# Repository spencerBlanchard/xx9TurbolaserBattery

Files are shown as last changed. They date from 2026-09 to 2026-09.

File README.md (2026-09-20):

# xx9TurbolaserBattery
Welcome to the XX-9 Heavy Turbolaser Battery. This was originally made to have audio but the module I was using had a small delay, which kind of killed the gameplay so I got rid of it completely. 
Vibe Coded. 
Runs on esp32 dev kit

A NOTE ABOUT USING THE SERVOS: the MG90S servos are continuous servos, which means you have to spend a gutwrenching number of hours calibrating them. If you want to redo the code and use positional servos, that's probably easier, but my wife says I'm not allowed to spend any more money on this project. 

Parts list if you want to build your own:

Heat Set Threaded Inserts:
https://www.amazon.com/dp/B0CS6VZYL8?ref=ppx_yo2ov_dt_b_fed_asin_title&th=1

Screws (for the inserts):
https://www.amazon.com/dp/B0FLKCP52N?ref=ppx_yo2ov_dt_b_fed_asin_title

-SG90 servo (1)
https://www.amazon.com/MELIFE-Micro-Servo-Plastic-Digital/dp/B0GTPGBW23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

-MG90S Servos (2)
https://www.amazon.com/Compatible-Raspberry-Project-Helicopter-Airplane/dp/B0925V3X2S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

-Joystick
https://www.adafruit.com/product/480

-Buttons
https://www.aliexpress.us/item/2251832838113879.html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

-TFT Display (also get the breakout board and ribbon)
https://www.adafruit.com/product/2090

(And resistors and wire and green leds and protoboard)

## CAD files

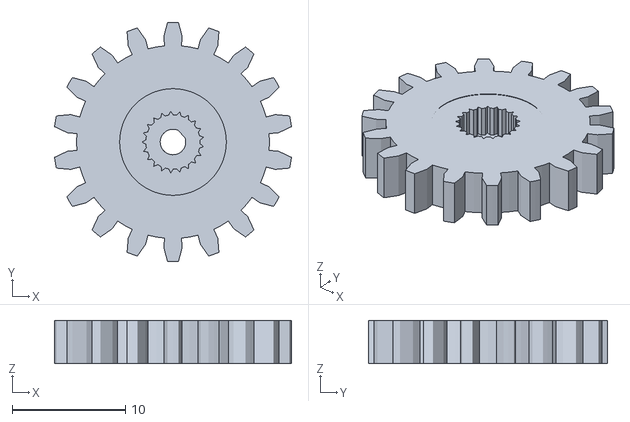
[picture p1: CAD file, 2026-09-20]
print_files/gear_yaw_v01.stl
20.9 x 21.1 x 3.81

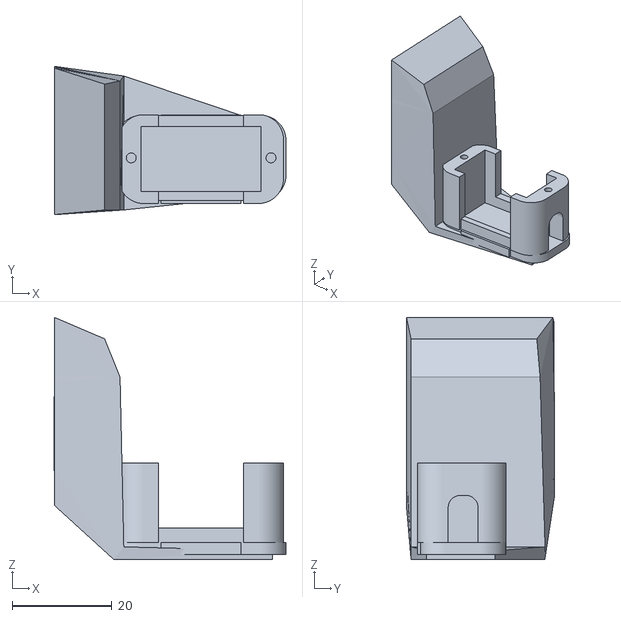
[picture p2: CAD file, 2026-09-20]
print_files/yawTopAddon_v01.stl
46.5 x 29.7 x 48.5

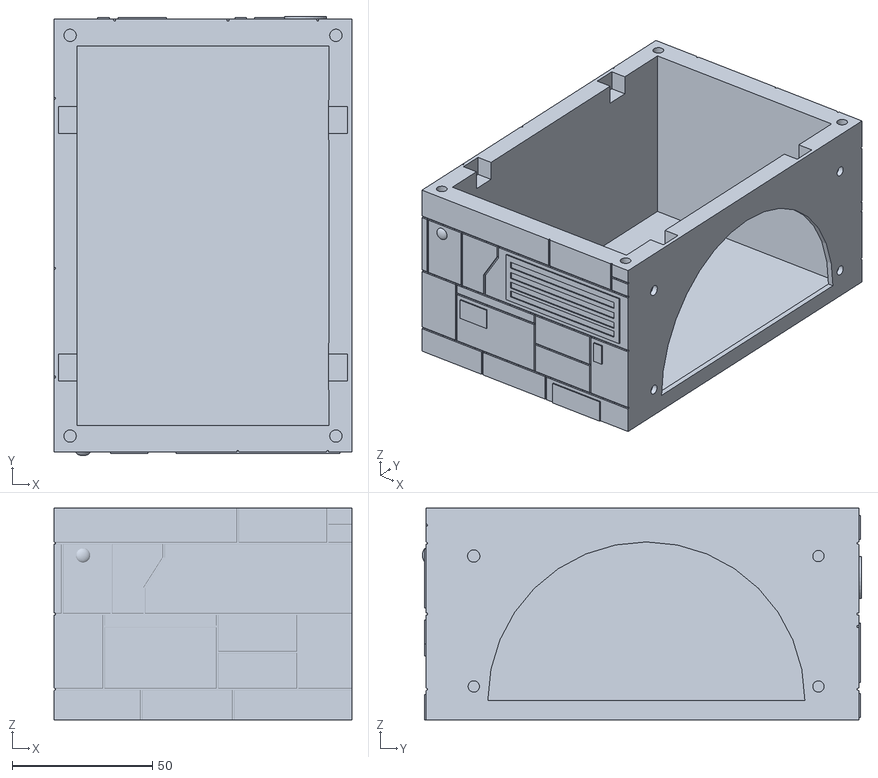
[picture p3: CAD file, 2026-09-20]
print_files/base_side_left_v01.stl
106.2 x 156.5 x 75.5

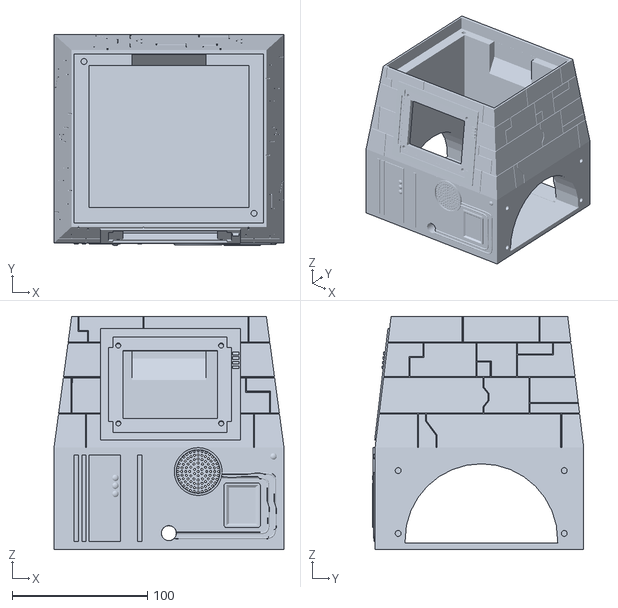
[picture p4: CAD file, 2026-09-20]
print_files/Base_v01.stl
170.1 x 156.4 x 172.4

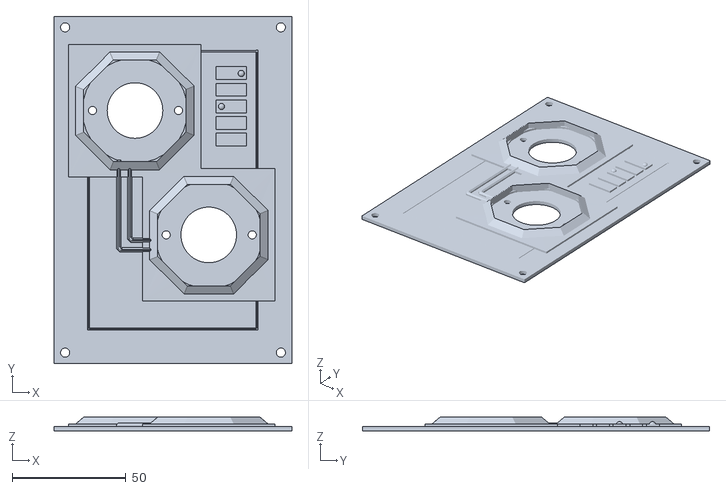
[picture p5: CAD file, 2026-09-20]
print_files/sideTop_buttons_v02.stl
104.3 x 152.3 x 6.06

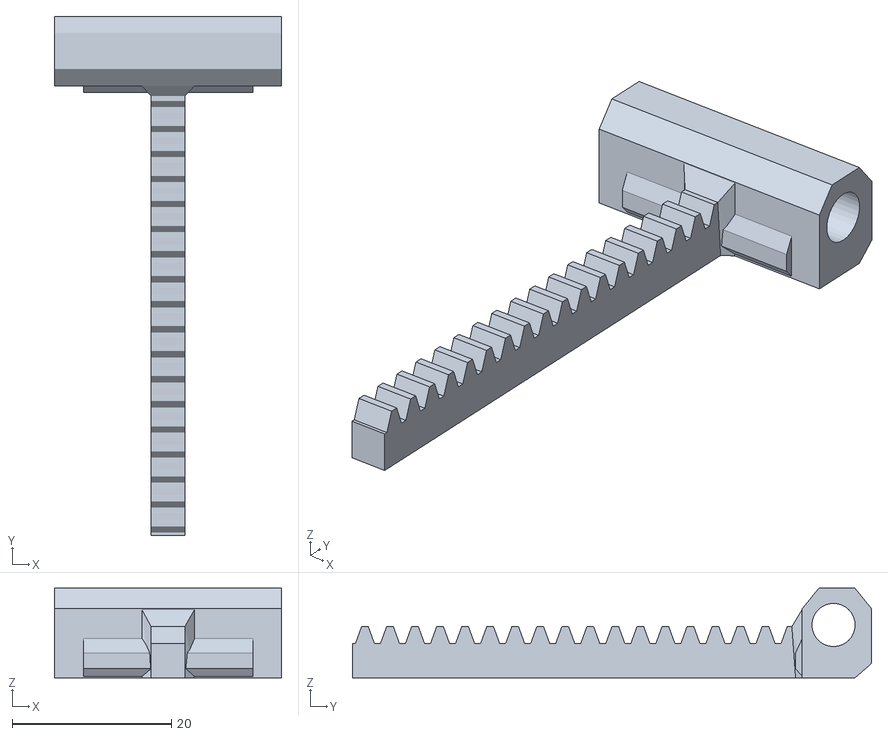
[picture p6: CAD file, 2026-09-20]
print_files/gear_linearActuator_straight_v01.stl
28.5 x 65.1 x 11.3

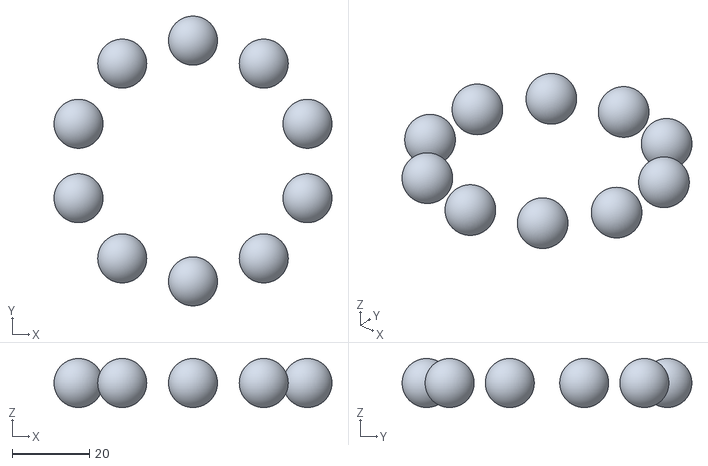
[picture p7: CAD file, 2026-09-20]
print_files/balls_v01.stl
72.0 x 75.1 x 12.7

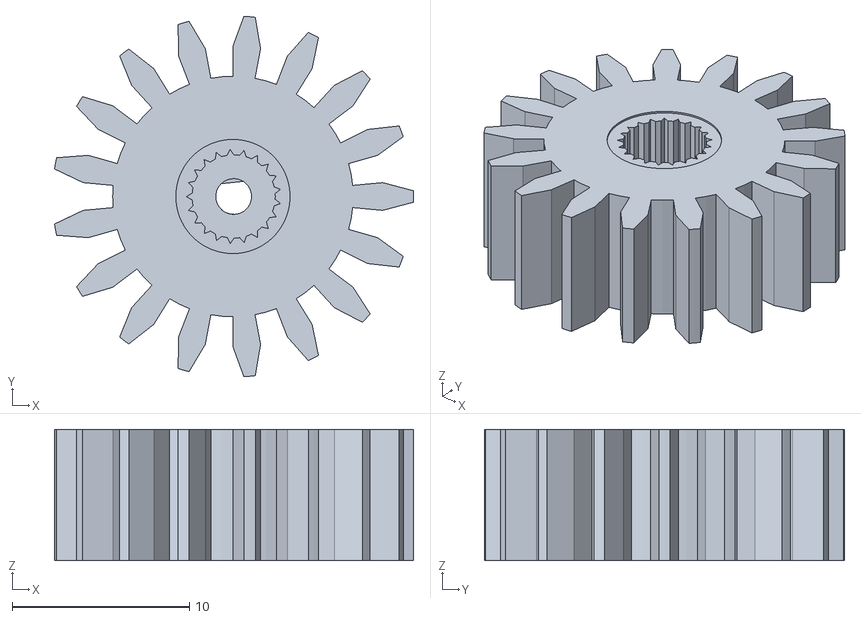
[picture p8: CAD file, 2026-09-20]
print_files/gear_pitch_v01.stl
20.2 x 20.3 x 7.40

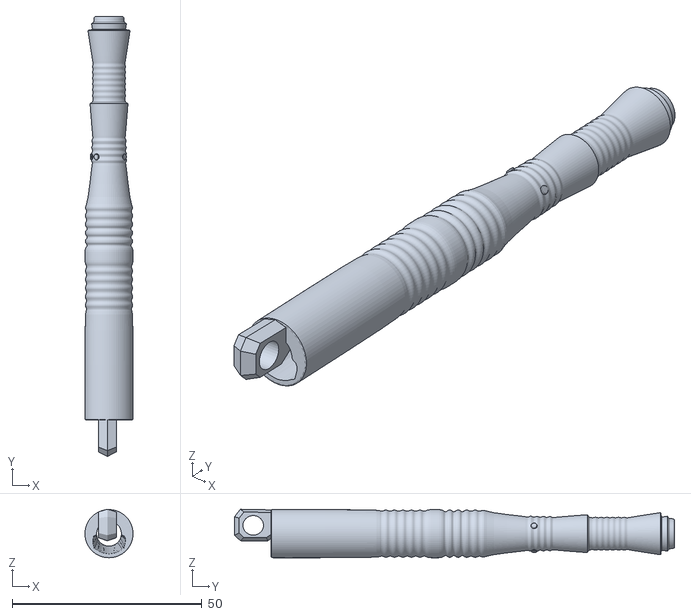
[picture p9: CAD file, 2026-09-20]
print_files/cannon_v01.stl
12.7 x 116.1 x 12.8

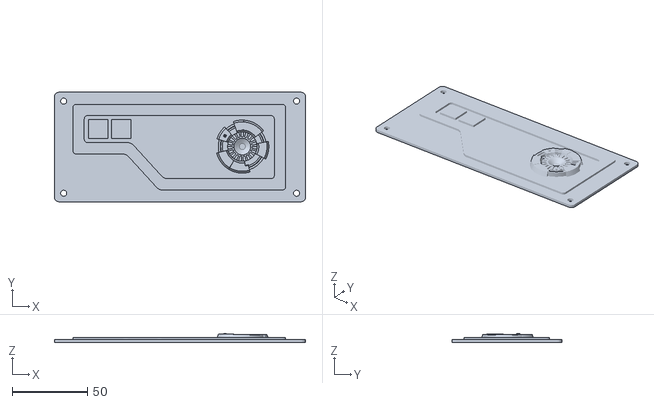
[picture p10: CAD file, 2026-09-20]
print_files/wires_cover_plate_v01.stl
166.4 x 72.6 x 6.08

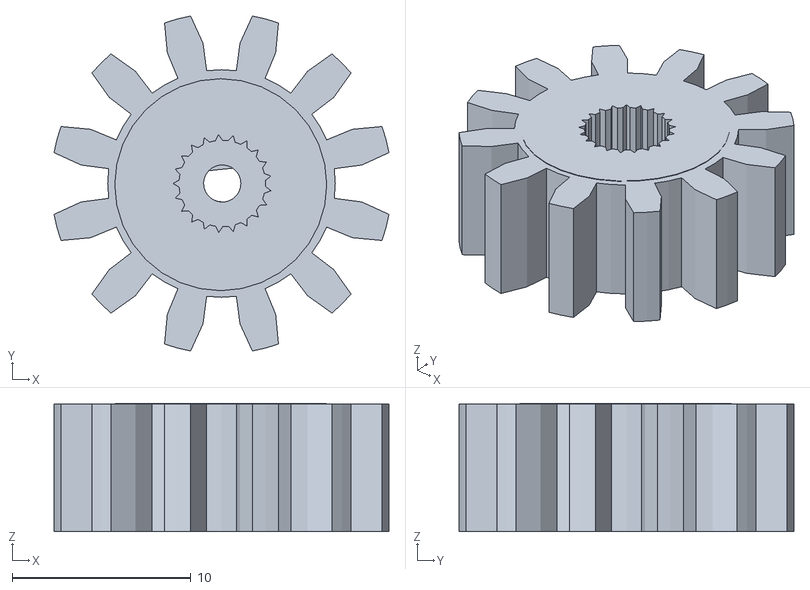
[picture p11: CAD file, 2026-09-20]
print_files/pitchGears_sizing_v06.stl
18.7 x 18.7 x 7.18

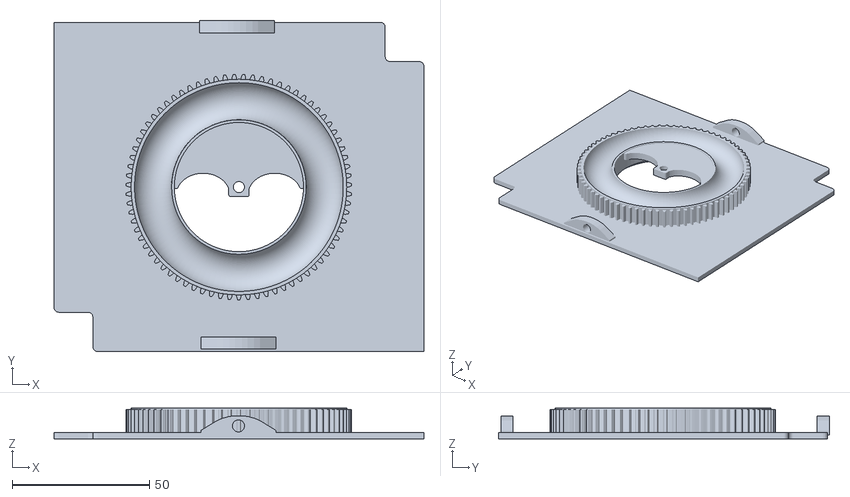
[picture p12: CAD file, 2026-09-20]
print_files/yawTop_v01.stl
134.9 x 120.7 x 11.3

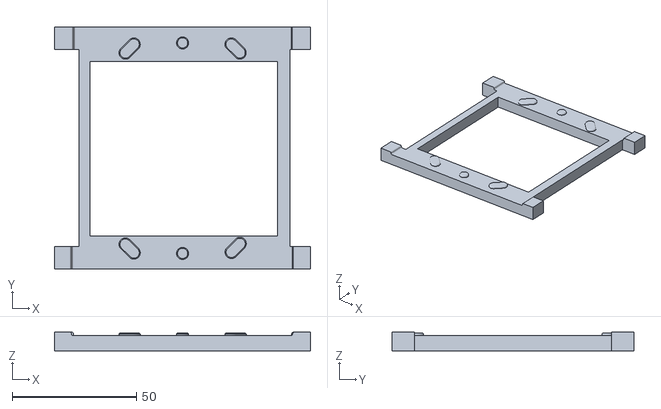
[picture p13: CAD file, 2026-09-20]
print_files/joystickHolder_v01.stl
102.9 x 97.2 x 7.50

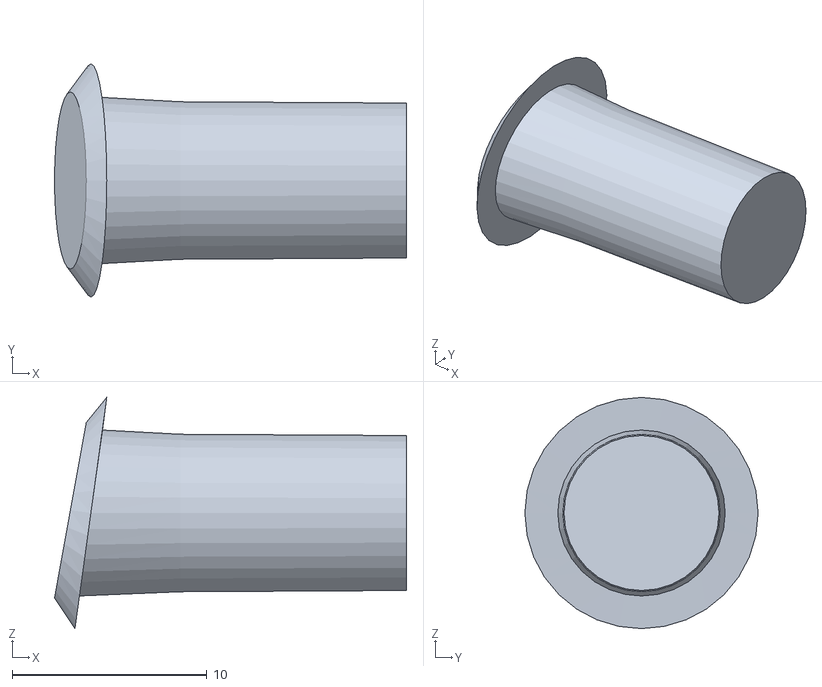
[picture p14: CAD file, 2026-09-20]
print_files/ears_v007.stl
18.1 x 12.0 x 11.9

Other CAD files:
print_files/BaseWithLadder_v01.stl
print_files/sideTop_joystick_v02.stl
print_files/base_side_right_v01.stl
print_files/rod_v01.stl
print_files/gear_linearActuator_round_v01.stl
print_files/sideTop_buttons_v01.stl
print_files/sideTop_joystick_v01.stl
print_files/yawBottom_v01.stl
print_files/yawBottom_v02.stl

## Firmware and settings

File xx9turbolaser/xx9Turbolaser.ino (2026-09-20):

// ============================================================
// ESP32 TURRET GAME
// Adafruit 2.8" ILI9341 TFT
//
// MAXIMUM-LATENCY-OPTIMIZED AUDIO VERSION:
//   Button detection + DFPlayer commands run on ESP32 Core 0.
//   GPIO interrupts wake the audio task immediately.
//   DFPlayer packets are written directly to UART with NO library
//   command delay and NO ACK wait.
//   Root-folder playback is used for the shortest command path.
//
// PLAYER:
//   Left / Right = aim line + physical left/right servo
//   Up / Down    = elevation marker + physical up/down servo
//
// ENEMY:
//   Normal and shielded X-wing sprites move through the aim section
//   A matching horizontal marker shows enemy elevation on the left
//
// HEALTH:
//   Three hearts at the top-right
//   3 missed enemies = GAME OVER
//
// BUTTON / LED SYSTEM:
//
//   GREEN BUTTON = GPIO35
//   RED BUTTON   = GPIO34
//
//   GREEN LED     = GPIO32
//   RED LED       = GPIO33
//   ANIMATION LED = GPIO25
//
// NORMAL:
//   Both LEDs ON
//
// GREEN BUTTON:
//   Both LEDs OFF for at least 1 second
//
// RED BUTTON:
//   Green LED OFF for at least 2 seconds
//   Red LED OFF for at least 4 seconds
//
// BUTTON RE-ARM:
//   A button remains disabled for 80ms AFTER its corresponding
//   LED comes back on.
//
//   This guarantees that even when buttons are spammed,
//   you will visibly see the LED illuminate before another
//   valid button press can occur.
//
// IMPORTANT:
//   GPIO34 and GPIO35 require EXTERNAL pull-up resistors.
// ============================================================


#include <SPI.h>
#include <Adafruit_GFX.h>
#include <Adafruit_ILI9341.h>
#include <Wire.h>
#include <Adafruit_PWMServoDriver.h>
#include <freertos/FreeRTOS.h>
#include <freertos/task.h>
#include <Preferences.h>
#include "calibration_frames.h"
#include <math.h>
#include "background_bitmap.h"
#include "start_menu_background_bitmap.h"
#include "xwing_sprites.h"


// Set to 1 only while debugging. Keeping this at 0 removes
// Serial printing from the time-critical button/audio path.
#define BUTTON_AUDIO_DEBUG 0


// ============================================================
// TFT PINS
// ============================================================

#define TFT_CS   5
#define TFT_DC   2
#define TFT_RST  4


// ============================================================
// JOYSTICK PINS
// ============================================================

#define PIN_UP     26
#define PIN_DOWN   27
#define PIN_LEFT   14
#define PIN_RIGHT  13


// ============================================================
// BUTTON PINS
// ============================================================
//
// GPIO34 / GPIO35 do NOT have internal pull-ups.
//
// Wiring:
//
// 3.3V
//   |
//  10k
//   |
//   +------ GPIO34 / GPIO35
//   |
// BUTTON
//   |
//  GND
//
// ============================================================

#define PIN_RED_BUTTON    34
#define PIN_GREEN_BUTTON  35


// ============================================================
// LED PINS
// ============================================================

#define PIN_GREEN_LED      32
#define PIN_RED_LED        33
#define PIN_ANIMATION_LED  25


// ============================================================
// DFPLAYER MINI
// ============================================================
//
// DFPlayer TX -> ESP32 GPIO16 (RX2)
// ESP32 GPIO17 (TX2) -> 1k resistor -> DFPlayer RX
//
// FILES ARE IN THE ROOT OF THE SD CARD:
//   /0001.wav   (or /0001.mp3)
//   /0002.wav   (or /0002.mp3)
//   /0003.wav   (or /0003.mp3)
//   /0004.wav   (or /0004.mp3)
//
// IMPORTANT FOR dfPlayer-style root indexing:
// Root track numbers follow the FAT/copy order on the SD card.
// For predictable 1/2/3/4 mapping, use a freshly formatted card
// and copy 0001, then 0002, then 0003, then 0004.
//
// This version intentionally does NOT use DFRobotDFPlayerMini.
// It sends the 10-byte DFPlayer UART packet directly so there is
// no library-imposed delay before/after each play command.
// ============================================================

#define DFPLAYER_RX  16
#define DFPLAYER_TX  17

HardwareSerial dfSerial(2);

bool dfPlayerReady = false;


// ============================================================
// PCA9685 SERVO CONTROLLER
// ============================================================
//
// PCA9685 wiring:
//   VCC -> ESP32 3.3V
//   GND -> common GND
//   SDA -> ESP32 GPIO21
//   SCL -> ESP32 GPIO22
//   V+  -> external 5V servo supply
//
// Servo channel assignments:
//   channel 0 = SG90 button animation servo
//   channel 1 = up/down continuous-rotation MG90S
//   channel 2 = left/right continuous-rotation MG90S
// ============================================================

#define PCA9685_SDA 21
#define PCA9685_SCL 22

Adafruit_PWMServoDriver pwm = Adafruit_PWMServoDriver(0x40);

const uint8_t ANIMATION_SERVO_CHANNEL = 0;
const uint8_t UD_SERVO_CHANNEL = 1;
const uint8_t LR_SERVO_CHANNEL = 2;

// ============================================================
// CALIBRATED CONTINUOUS-ROTATION SERVO VALUES
// ============================================================
// These are raw PCA9685 ticks at 50 Hz.
// We use raw ticks instead of converting from microseconds because
// the calibration showed that a one-tick change matters around neutral.
//
// LEFT / RIGHT servo (channel 2):
//   left  = 353
//   stop  = 373
//   right = 383
//
// UP / DOWN servo (channel 1):
//   up    = 380
//   stop  = 370
//   down  = 350
// ============================================================

const uint16_t LR_LEFT_TICKS  = 351;
const uint16_t LR_STOP_TICKS  = 370;
const uint16_t LR_RIGHT_TICKS = 381;

const uint16_t UD_UP_TICKS    = 395;
const uint16_t UD_STOP_TICKS  = 369;
const uint16_t UD_DOWN_TICKS  = 354;

// Cache the last command so we do not repeatedly rewrite the same
// PCA9685 value every frame. -1 means no command has been sent yet.
int lastLRServoTicks = -1;
int lastUDServoTicks = -1;

// ============================================================
// LEFT / RIGHT DIGITAL TRAVEL LIMIT
// ============================================================
// The turret is assumed to be physically centered every time the
// program starts. We then track its estimated horizontal position
// purely by how long the continuous-rotation servo has been moving.
//
// Center = 0 ms
// Full left limit  = -1500 ms from center
// Full right limit = +1500 ms from center
//
// Therefore a complete left-to-right sweep is approximately 3000 ms.
// This is an open-loop/software limit: if the turret is moved by hand
// or slips mechanically, the program cannot detect that.
// ============================================================

const int32_t LR_TRAVEL_LIMIT_MS = 1500;

// Signed estimated horizontal position, expressed as equivalent
// milliseconds of servo travel from the startup center position.
int32_t lrTravelPositionMs = 0;

// Direction that was actually commanded during the interval since
// the previous update: -1 = left, 0 = stopped, +1 = right.
int8_t lrPreviousMoveDirection = 0;

unsigned long lrLastTravelUpdateMs = 0;

// ============================================================
// UP / DOWN DIGITAL TRAVEL LIMIT
// ============================================================
// The turret is assumed to be physically centered vertically when the
// game starts. We track vertical position only by how long the continuous-
// rotation servo has actually been commanded to move.
//
// Center = 0 ms
// Full up limit   = -1000 ms from center
// Full down limit = +1000 ms from center
//
// This makes the complete physical top-to-bottom command-time sweep
// exactly 2.0 seconds, matching the TFT elevation marker.
// ============================================================

const int32_t UD_TRAVEL_LIMIT_MS = 1000;

// Signed estimated vertical position, expressed as equivalent
// milliseconds of servo travel from the startup center position.
// Negative = up, positive = down.
int32_t udTravelPositionMs = 0;

// Direction actually commanded during the interval since the previous
// update: -1 = up, 0 = stopped, +1 = down.
int8_t udPreviousMoveDirection = 0;

unsigned long udLastTravelUpdateMs = 0;

// Conservative SG90 pulse range at 50 Hz.
// If the servo mechanically binds near either endpoint, reduce
// SERVO_MAX_PULSE or increase SERVO_MIN_PULSE.
const uint16_t SERVO_MIN_PULSE = 110;
const uint16_t SERVO_MAX_PULSE = 500;

// This recreates the earlier recoil-style SG90 animation:
// rest around 70 degrees, make a small preload toward 65,
// snap to 180, then smoothly return to 70 over 350 ms.
const float SERVO_REST_ANGLE    = 70.0f;
const float SERVO_PRELOAD_ANGLE = 65.0f;
const float SERVO_KICK_ANGLE    = 180.0f;

const unsigned long SERVO_PRELOAD_MS   = 70;
const unsigned long SERVO_KICK_HOLD_MS = 20;
const unsigned long SERVO_RETURN_MS    = 350;

enum ServoAnimationState {
  SERVO_ANIM_IDLE,
  SERVO_ANIM_PRELOAD,
  SERVO_ANIM_KICK_HOLD,
  SERVO_ANIM_RETURN
};

ServoAnimationState servoAnimationState = SERVO_ANIM_IDLE;
unsigned long servoAnimationStateStart = 0;
float servoCurrentAngle = SERVO_REST_ANGLE;
float servoPreloadStartAngle = SERVO_REST_ANGLE;

// Red-button recoil plays at half speed (2x duration).
// Green-button recoil uses the normal timing.
float servoAnimationTimeScale = 1.0f;


// ============================================================
// TFT
// ============================================================

Adafruit_ILI9341 tft(
  TFT_CS,
  TFT_DC,
  TFT_RST
);


// ============================================================
// BUTTON / LED TIMEOUT SYSTEM
// ============================================================

// Green button:
//
// Both LEDs remain off for 1 second.
const unsigned long GREEN_BUTTON_TIMEOUT_MS = 1000;


// Red button:
//
// Green LED returns after 2 seconds.
// Red LED returns after 4 seconds.
const unsigned long RED_BUTTON_GREEN_TIMEOUT_MS = 2000;
const unsigned long RED_BUTTON_RED_TIMEOUT_MS   = 4000;

// Activated by the one-time S+ target in absolute round 6.
volatile bool turbolaserSpeedBoostActive = false;
const float SPEED_BOOST_COOLDOWN_MULTIPLIER = 0.75f;


// Button remains disabled this much longer
// AFTER its corresponding LED returns.
const unsigned long BUTTON_REARM_DELAY_MS = 80;


// ------------------------------------------------------------
// LED timeout timestamps
// ------------------------------------------------------------

unsigned long greenLedOffUntil = 0;
unsigned long redLedOffUntil   = 0;


// ------------------------------------------------------------
// Button re-enable timestamps
// ------------------------------------------------------------

unsigned long greenButtonDisabledUntil = 0;
unsigned long redButtonDisabledUntil   = 0;


// ------------------------------------------------------------
// Previous physical button states
//
// These allow us to detect the transition:
//
// RELEASED -> PRESSED
//
// Holding a button down does NOT repeatedly fire.
// ------------------------------------------------------------

bool previousGreenButton = false;
bool previousRedButton   = false;


// ------------------------------------------------------------
// ACCEPTED BUTTON PRESSES
//
// These become true for ONE loop iteration only when a valid
// shot/button press is accepted.
//
// Later, use THESE variables for the actual shooting gameplay.
//
// DO NOT use digitalRead() directly for shooting.
// ------------------------------------------------------------

bool greenButtonPressedThisFrame = false;
bool redButtonPressedThisFrame   = false;
bool redButtonCooldownPressedThisFrame = false;


// ============================================================
// DUAL-CORE BUTTON / AUDIO TASK
// ============================================================
//
// The normal Arduino loop and TFT rendering run independently
// from this task. The button/audio task is pinned to Core 0.
// GPIO FALLING-edge interrupts wake it immediately, so a long
// TFT draw on the main loop does not postpone the DFPlayer
// command and the task does not have to wait for its 1 ms tick.
//
// Accepted button presses are queued here so the main loop can
// still consume them later for shooting/gameplay without losing
// an event.
// ============================================================

TaskHandle_t buttonAudioTaskHandle = nullptr;
bool buttonAudioTaskStarted = false;

// Both button GPIOs use FALLING-edge interrupts. The ISR does no
// audio work itself; it only wakes the Core-0 task immediately.
// This avoids waiting for the next 1 ms polling interval.
volatile bool buttonWakeInterruptsAttached = false;

portMUX_TYPE buttonEventMux = portMUX_INITIALIZER_UNLOCKED;
volatile uint32_t pendingGreenPresses = 0;
volatile uint32_t pendingRedPresses   = 0;
volatile uint32_t pendingRedCooldownPresses = 0;


// ============================================================
// RIGHT / AIM SECTION
// ============================================================

const int RECT_LEFT   = 49;
const int RECT_RIGHT  = 306;
const int RECT_TOP    = 16;
const int RECT_BOTTOM = 225;

const int MARGIN = 3;
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
void loop() {

  // ==========================================================
  // BUTTON / AUDIO EVENTS
  //
  // Normally the physical buttons, LEDs, and DFPlayer are all
  // handled independently on Core 0.
  //
  // If the FreeRTOS task failed to start for any reason, this
  // fallback keeps the buttons working from the main loop.
  // ==========================================================

  if (!buttonAudioTaskStarted) {

    updateButtonsAndLeds();
  }


  // Pull any accepted button events into the familiar
  // one-frame flags for future shooting/gameplay logic.
  consumeButtonEvents();


  // ==========================================================
  // GAME OVER CONTROL MODE
  // ==========================================================
  // Buttons, LEDs, and audio may continue on Core 0, but return before
  // any SG90 animation or joystick-servo command can be generated.
  // All PCA9685 servo channels were placed in FULL OFF by showGameOver().

  if (gameOver) {

    delay(
      10
    );

    return;
  }


  // ==========================================================
  // SG90 BUTTON ANIMATION
  //
  // Either ACCEPTED button press restarts the recoil animation.
  // This is intentionally non-blocking so TFT/game/audio timing
  // continues normally while the servo moves.
  // ==========================================================

  if (redButtonPressedThisFrame) {

    // Half speed = twice the normal animation duration.
    triggerServoAnimation(2.0f);
  }
  else if (greenButtonPressedThisFrame) {

    triggerServoAnimation(1.0f);
  }


  updateServoAnimation();


  // ==========================================================
  // READ JOYSTICK
  // ==========================================================

  bool up =
    (
      digitalRead(PIN_UP)
      == LOW
    );


  bool down =
    (
      digitalRead(PIN_DOWN)
      == LOW
    );


  bool left =
    (
      digitalRead(PIN_LEFT)
      == LOW
    );


  bool right =
    (
      digitalRead(PIN_RIGHT)
      == LOW
    );


  // Move the calibrated continuous-rotation servos from the same joystick.
  updateJoystickServos(
    left,
    right,
    up,
    down
  );


  bool aimChanged =
    false;


  bool tickChanged =
    false;


  // ==========================================================
  // PLAYER AIM - SYNCHRONIZED TO PHYSICAL LR TURRET
  // ==========================================================
  // The physical LR turret already tracks its estimated position as
  // elapsed movement time from the startup center:
  //
  //   -1500 ms = full left  = -75 degrees on TFT
  //       0 ms = center     =   0 degrees on TFT
  //   +1500 ms = full right = +75 degrees on TFT
  //
  // Because both the physical limit and the display use the SAME
  // lrTravelPositionMs value, a complete left-to-right sweep takes
  // exactly 3000 ms and the TFT line stays synchronized with the
  // software-estimated physical turret position.

  float newAimAngleDeg =
    ((float)lrTravelPositionMs / (float)LR_TRAVEL_LIMIT_MS)
    * MAX_ANGLE_DEG;

  newAimAngleDeg = constrain(
    newAimAngleDeg,
    -MAX_ANGLE_DEG,
    MAX_ANGLE_DEG
  );

  if (fabsf(newAimAngleDeg - aimAngleDeg) > 0.001f) {
    aimAngleDeg = newAimAngleDeg;
    aimChanged = true;
  }


  // ==========================================================
  // PLAYER HEIGHT - SYNCHRONIZED TO PHYSICAL UP/DOWN TURRET
  // ==========================================================
  // The physical UD turret tracks its estimated position as elapsed
  // movement time from the startup center:
  //
  //   -1000 ms = full up   = TICK_Y_MIN
//       0 ms = center    = middle of the elevation bar
  //   +1000 ms = full down = TICK_Y_MAX
  //
  // Both the physical servo limit and the TFT elevation marker use the
  // SAME udTravelPositionMs value, so a full top-to-bottom sweep takes
  // exactly 2000 ms and the display stays synchronized with the
  // software-estimated physical turret position.

  float udNormalized =
    ((float)udTravelPositionMs + (float)UD_TRAVEL_LIMIT_MS) /
    (2.0f * (float)UD_TRAVEL_LIMIT_MS);

  udNormalized = constrain(udNormalized, 0.0f, 1.0f);

  int newTickY =
    (int)roundf(
      (float)TICK_Y_MIN +
      udNormalized * (float)(TICK_Y_MAX - TICK_Y_MIN)
    );

  newTickY = constrain(
    newTickY,
    TICK_Y_MIN,
    TICK_Y_MAX
  );

  if (newTickY != tickY) {
    tickY = newTickY;
    tickChanged = true;
  }


  // ==========================================================
  // SHOOTING / HIT DETECTION
  // ==========================================================
  // Green-button shots deal 1 damage. Red-button shots deal 3 damage.
  // Shielded X-wings have 3 HP and switch to the normal sprite after
  // two green hits leave them at 1 HP. Normal X-wings have 1 HP.
  // Every hit still requires BOTH horizontal aim and elevation alignment.

  int shotDamage = 0;

  if (redButtonPressedThisFrame) {
    shotDamage = 3;
  }
  else if (greenButtonPressedThisFrame) {
    shotDamage = 1;
  }

  bool shieldedTargetPresent =
    (primaryEnemyActive && enemyIsRed) ||
    (enemy2Active && enemy2IsRed);

  // Remember which shielded round started the current red cooldown.
  if (redButtonPressedThisFrame && shieldedTargetPresent) {
    lastAcceptedRedOnShieldedShip = enemyShipNumber;
  }

  if (
    selectedDifficulty == DIFFICULTY_NORMAL &&
    redButtonCooldownPressedThisFrame &&
    shieldedTargetPresent &&
    lastAcceptedRedOnShieldedShip == enemyShipNumber
  ) {
    if (!redCooldownHintShown) {
      redCooldownHintShown = true;
      firstRedCooldownHintShipNumber = enemyShipNumber;
      showTutorialMessage(TUTORIAL_RED_COOLDOWN);
    }
    else if (
      !buttonLightsHintShown &&
      enemyShipNumber != firstRedCooldownHintShipNumber
    ) {
      buttonLightsHintShown = true;
      showTutorialMessage(TUTORIAL_BUTTON_LIGHTS);
    }
  }

  if (
    shotDamage > 0
  ) {
    // The S+ target requires horizontal/side-to-side aim only and consumes
    // this shot before enemy hit-testing.
    if (shotHitsSpeedBoost()) {
      eraseSpeedBoostTarget();
      speedBoostTargetActive = false;
      turbolaserSpeedBoostActive = true;

      // Apply the boost to the activating shot's cooldown as well as every
      // later shot, so the benefit is immediately visible on the LEDs.
      unsigned long boostNow = millis();
      if ((long)(greenLedOffUntil - boostNow) > 0) {
        greenLedOffUntil = boostNow + (unsigned long)(
          (greenLedOffUntil - boostNow) * SPEED_BOOST_COOLDOWN_MULTIPLIER
        );
      }
      if ((long)(redLedOffUntil - boostNow) > 0) {
        redLedOffUntil = boostNow + (unsigned long)(
          (redLedOffUntil - boostNow) * SPEED_BOOST_COOLDOWN_MULTIPLIER
        );
      }
      greenButtonDisabledUntil = greenLedOffUntil + BUTTON_REARM_DELAY_MS;
      redButtonDisabledUntil = redLedOffUntil + BUTTON_REARM_DELAY_MS;

      showTutorialMessage(TUTORIAL_SPEED_BOOST);
    }
    else {
      bool primaryHorizontal = false;
      bool primaryVertical = false;
      bool secondaryHorizontal = false;
      bool secondaryVertical = false;

      if (primaryEnemyActive && !enemyHitAnimating) {
        getShotAlignment(primaryHorizontal, primaryVertical);
      }
      if (enemy2Active && !enemy2HitAnimating) {
        getEnemy2ShotAlignment(secondaryHorizontal, secondaryVertical);
      }

      bool primaryHit = primaryHorizontal && primaryVertical;
      bool secondaryHit = secondaryHorizontal && secondaryVertical;

      // Easy-mode hints explain the relevant mistake without pausing play.
      if (selectedDifficulty == DIFFICULTY_NORMAL) {
        if (
          enemyShipNumber <= 2 &&
          ((primaryHorizontal && !primaryVertical) ||
           (secondaryHorizontal && !secondaryVertical)) &&
          lastElevationHintShipNumber != enemyShipNumber
        ) {
          lastElevationHintShipNumber = enemyShipNumber;
          showTutorialMessage(TUTORIAL_ELEVATION);
        }

        if (
          enemyShipNumber == 3 &&
          greenButtonPressedThisFrame &&
          !shieldHintShown
        ) {
          shieldHintShown = true;
          showTutorialMessage(TUTORIAL_SHIELD);
        }
      }

      if (primaryHit) {
        beginEnemyHit(shotDamage);
      }
      else if (secondaryHit) {
        beginEnemy2Hit(shotDamage);
      }
    }
  }


  // ==========================================================
  // ERASE OLD DYNAMIC GRAPHICS
  // ==========================================================

  eraseOldEnemy();
  eraseOldEnemy2();


  if (aimChanged) {

    restoreBackgroundRect(

      prevLineX0,
      prevLineY0,

      prevLineX1,
      prevLineY1
    );
  }


  if (tickChanged) {

    restoreBackgroundRect(
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

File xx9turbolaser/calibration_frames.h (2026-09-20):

#pragma once
#include <Arduino.h>
const int CALIBRATION_WIDTH = 124;
const int CALIBRATION_HEIGHT = 147;
const int CALIBRATION_X = 98;
const int CALIBRATION_Y = 46;
const uint16_t CAL_FRAME_0[] PROGMEM = {
  1853,0,1,65,1,4423,1,6766,1,131,119,0,1,98,1,10992,
  1,8912,1,6667,1,6799,118,0,1,2310,1,11025,1,11058,1,2408,
  1,0,1,6700,1,4588,1,33,115,0,1,2408,1,8945,1,2375,
  1,2278,1,8945,1,99,1,66,1,8977,1,2342,113,0,1,33,
  1,4587,1,8846,1,132,2,0,1,2441,1,8879,1,66,1,2245,
  1,8945,1,2244,111,0,1,33,1,6733,1,8814,1,66,4,0,
  1,6700,1,6701,1,33,1,8846,1,8879,107,0,1,33,1,2375,
  1,6799,1,2245,1,8847,1,6700,1,33,5,0,1,65,1,8911,
  1,11090,1,11058,1,2211,106,0,1,2277,1,6799,1,8879,1,6766,
  1,13269,1,4620,7,0,1,2278,1,13171,1,8912,1,131,106,0,
  1,2343,1,13171,1,11091,1,98,1,33,1,8912,1,4522,6,0,
  1,2376,1,13204,1,6701,1,66,105,0,1,33,1,4522,1,8945,
  1,2311,1,6766,1,4554,1,0,1,131,1,8945,1,2310,3,0,
  1,32,1,6701,1,13236,1,4456,107,0,1,6700,1,6831,1,164,
  1,0,1,131,1,8977,1,2277,1,0,1,2244,1,8944,1,164,
  1,0,1,33,1,8813,1,11156,1,4456,106,0,1,98,1,8846,
  1,6667,4,0,1,2277,1,11025,1,131,1,0,1,4522,1,8945,
  1,2343,1,11026,1,10993,1,132,58,0,1,99,47,0,1,99,
  1,8911,1,6667,6,0,1,2376,1,6799,1,263,1,10992,1,13269,
  1,13237,1,8846,1,98,56,0,1,131,1,4489,1,8945,1,10959,
  1,10960,1,8977,1,6897,1,4685,1,4456,1,2310,1,2277,1,164,
  1,33,37,0,1,2343,1,8945,1,2408,8,0,1,11091,1,15415,
  1,15350,1,13269,1,6668,56,0,1,65,1,4587,1,8912,1,6700,
  1,2310,1,0,1,33,1,164,1,2343,1,4488,1,6569,1,6701,
  1,6864,1,8945,1,8847,1,8781,1,6667,1,2441,1,165,1,33,
  31,0,1,2376,1,8913,1,2343,7,0,1,66,1,6635,2,15382,
  1,13204,1,2441,55,0,1,2244,1,4620,1,8944,1,4620,1,131,
  9,0,1,65,1,66,1,98,1,197,1,4555,1,6798,1,8912,
  1,11058,1,11091,1,8977,1,6734,1,2343,1,2244,1,2212,1,99,
  1,33,21,0,1,33,1,4521,1,8912,1,98,7,0,1,131,
  1,8945,1,15382,1,13302,1,13171,1,131,54,0,1,2278,1,6733,
  1,8945,1,6602,1,131,15,0,1,2343,1,4521,1,6700,1,11026,
  1,13302,1,13269,1,13302,1,15350,1,15382,1,15350,1,11123,1,8879,
  1,8748,1,6634,1,2408,1,197,1,33,15,0,1,66,1,6668,
  1,8879,1,98,7,0,1,2244,1,11090,1,15415,1,15382,1,8912,
  1,131,52,0,1,33,1,2277,1,6798,1,8912,1,4456,1,98,
  13,0,1,2277,1,8912,1,11057,1,11025,1,8977,1,11091,1,13269,
  1,11091,1,4423,1,131,1,2244,1,4554,1,11123,1,8912,1,2311,
  1,4620,1,11090,1,15317,1,15383,1,15318,1,13138,1,10993,1,6798,
  1,4588,1,2277,1,131,1,98,1,66,1,33,6,0,1,131,
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
};
const uint16_t CAL_FRAME_1[] PROGMEM = {
  600,0,1,4456,1,2311,1,32,120,0,1,4521,1,11025,1,8879,
  1,8978,1,4489,118,0,1,4423,1,8944,1,131,1,98,1,11156,
  1,13236,1,2375,116,0,1,4489,1,8944,1,65,1,98,1,8879,
  1,4488,1,65,1,8912,1,2375,114,0,1,2278,1,8944,1,2212,
  1,65,1,6766,1,4587,2,0,1,2278,1,8945,1,197,112,0,
  1,2310,1,8945,1,164,1,33,1,4653,1,6701,1,33,3,0,
  1,2474,1,8912,1,33,3,0,1,2278,1,2277,1,98,104,0,
  1,132,1,8913,1,2376,1,33,1,4555,1,6799,1,66,3,0,
  1,98,1,6831,1,4489,3,0,1,2343,1,8945,1,6799,1,8912,
  1,6635,1,66,101,0,1,131,1,8880,1,2441,1,0,1,4489,
  1,8912,1,98,3,0,1,65,1,6766,1,4620,3,0,1,197,
  1,8912,1,262,1,33,1,4554,1,13237,1,6733,1,33,99,0,
  1,33,1,8846,1,4587,1,0,1,2310,1,8977,1,163,3,0,
  1,33,1,4620,1,6734,1,66,2,0,1,164,1,8912,1,2376,
  1,0,1,164,1,8913,1,2442,1,8814,1,6700,98,0,1,32,
  1,6733,1,6700,1,33,1,2310,1,8977,1,131,4,0,1,4522,
  1,6831,1,66,2,0,1,33,1,8912,1,4521,1,0,1,99,
  1,8879,1,4522,1,0,1,65,1,8846,1,2441,96,0,1,33,
  1,6733,1,6700,1,0,1,2277,1,11025,1,2244,4,0,1,4488,
  1,8912,1,98,2,0,1,98,1,8911,1,4489,1,0,1,66,
  1,8879,1,4554,3,0,1,33,1,8945,1,2376,95,0,1,4619,
  1,8813,1,33,1,164,1,8945,1,2245,4,0,1,2375,1,8977,
  1,131,3,0,1,8879,1,6635,2,0,1,8813,1,6700,1,33,
  4,0,1,8977,1,4554,93,0,1,33,1,4555,1,6766,1,1,
  1,164,1,8912,1,2343,4,0,1,4456,1,8945,1,98,2,0,
  1,66,1,6798,1,6602,1,0,1,65,1,6765,1,6668,4,0,
  1,65,1,6733,1,6667,94,0,1,2376,1,8912,1,131,1,98,
  1,6799,1,2442,4,0,1,2277,1,8944,1,2244,3,0,1,6701,
  1,6733,2,0,1,6700,1,8813,1,33,4,0,1,4588,1,6766,
  1,33,93,0,1,2311,1,8945,1,197,1,66,1,6798,1,4587,
  4,0,1,2278,1,8945,1,197,2,0,1,33,1,4587,1,6734,
  1,66,1,33,1,4587,1,6733,1,33,4,0,1,2442,1,6799,
  1,99,93,0,1,2245,1,8977,1,229,1,0,1,6700,1,6733,
  1,33,3,0,1,99,1,8913,1,2409,3,0,1,4522,1,8912,
  1,98,1,0,1,4522,1,6799,1,33,4,0,1,2409,1,8945,
  1,131,93,0,1,98,1,11025,1,2375,1,33,1,6667,1,6765,
  1,33,3,0,1,131,1,8880,1,2441,3,0,1,2408,1,8912,
  1,164,1,0,1,2376,1,8912,1,164,4,0,1,2310,1,8945,
  1,2245,93,0,1,163,1,8944,1,2343,1,0,1,6667,1,8846,
  1,33,4,0,1,8847,1,4620,3,0,1,2310,1,8945,1,164,
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
};
const uint16_t CAL_FRAME_2[] PROGMEM = {
  70,0,1,2343,1,8945,1,6831,1,4686,1,2474,1,2376,1,66,
  117,0,1,6831,1,4587,1,2408,1,4521,1,6700,1,13269,1,6701,
  116,0,1,65,1,8944,1,66,2,0,1,2212,1,11090,1,11058,
  1,66,13,0,1,2343,1,8912,1,6799,1,4685,1,2474,1,2343,
  1,132,95,0,1,4587,1,6668,3,0,1,4522,1,6634,1,4620,
  1,6634,13,0,1,8846,1,4521,1,2408,1,4554,1,6668,1,13171,
  1,10960,1,65,93,0,1,33,1,8912,1,99,3,0,1,8912,
  1,230,1,2343,1,8780,12,0,1,164,1,8977,1,33,3,0,
  1,10992,1,13204,1,2245,93,0,1,2375,1,8912,3,0,1,2310,
  1,8879,1,0,1,8847,1,2376,12,0,1,4456,1,4620,3,0,
  1,197,1,8944,1,4587,1,4554,93,0,1,4587,1,4456,3,0,
  1,6700,1,2441,1,66,1,8944,1,33,12,0,1,6831,1,4423,
  3,0,1,6602,1,4620,1,4488,1,6832,92,0,1,65,1,8945,
  1,164,2,0,1,131,1,8912,1,98,1,4521,1,6701,12,0,
  1,66,1,8944,1,66,2,0,1,65,1,6831,1,2244,1,6635,
  1,2376,92,0,1,230,1,8814,3,0,1,2309,1,6766,1,66,
  1,6798,1,2277,12,0,1,2441,1,6733,3,0,1,2211,1,6864,
  1,164,1,8945,1,2244,92,0,1,6798,1,2408,3,0,1,6766,
  1,4456,1,2212,1,8912,1,98,12,0,1,8911,1,164,3,0,
  1,4522,1,6635,1,2244,1,8846,1,33,91,0,1,131,1,8944,
  1,33,3,0,1,10992,1,98,1,4489,1,6635,12,0,1,2277,
  1,8977,4,0,1,8912,1,2310,1,6701,1,4554,92,0,1,4521,
  1,4653,3,0,1,4489,1,6733,1,0,1,8912,1,2310,12,0,
  1,4521,1,4555,3,0,1,164,1,8912,1,33,1,10960,1,99,
  91,0,1,65,1,8879,1,2244,2,0,1,33,1,8879,1,165,
  1,229,1,8911,12,0,1,33,1,6831,1,2309,3,0,1,6635,
  1,4555,1,2375,1,8912,92,0,1,2212,1,8912,1,98,2,0,
  1,2277,1,8945,1,32,1,6700,1,2474,12,0,1,98,1,8879,
  1,66,2,0,1,65,1,8847,1,163,1,6667,1,2408,92,0,
  1,4588,1,6634,3,0,1,4521,1,4522,1,99,1,8945,1,98,
  12,0,1,4555,1,6667,3,0,1,2277,1,6864,1,196,1,8945,
  1,163,92,0,1,8912,1,197,3,0,1,6864,1,2310,1,2277,
  1,6766,1,33,12,0,1,8911,1,164,3,0,1,2441,1,4554,
  1,2244,1,6766,1,33,91,0,1,2376,1,8879,3,0,1,131,
  1,8879,1,33,1,4686,1,4488,12,0,1,2343,1,8912,4,0,
  1,8945,1,2310,1,6766,1,4521,92,0,1,6700,1,2376,3,0,
  1,6700,1,4587,1,0,1,8945,1,164,12,0,1,6602,1,4522,
  3,0,1,99,1,8912,1,33,1,8944,1,131,91,0,1,131,
  1,8945,1,98,2,0,1,66,1,10992,1,33,1,2409,1,8814,
  12,0,1,66,1,8912,1,2244,3,0,1,6668,1,4587,1,2376,
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
};
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

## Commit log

2026-09-13 Implement joystick-controlled aim line and elevation tick
    This code implements an ESP32-based application that controls a graphical interface with a joystick. It features a pivoting aim line and an elevation tick on a TFT display, responding to joystick inp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
2026-09-15 more game code
    more game code. Up down servo not quite dialed in yet. game getting there
2026-09-20 uploading stls for printing
    [BaseWithLadder_v01.stl, Base_v01.stl, balls_v01.stl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]
2026-09-20 Uploading STL files
    [BaseWithLadder_v01.stl, Base_v01.stl, balls_v01.stl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]
2026-09-20 Update README with parts list and servo notes
    Added detailed parts list and notes about servo usage.
